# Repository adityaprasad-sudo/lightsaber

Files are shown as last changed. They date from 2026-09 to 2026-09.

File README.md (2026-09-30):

# LightSaber

Pretty much everyone knows what a light saber is Well i am here to make it huhuhaha and share how to make it for #pixl.

# Code

The code is pretty simple and can be found inside the code folder in the GitHub repo you might want to calibrate your sensor(MPU_6050) to match your likings (Calibration is Important).

You can also adjust the thresholds required for a specific action to play. For ex: you can increase the clash threshold to active sound_clash on higher level of impact.

You can also change the color of clash and light saber and add as many modes as you want(as long as your esp32 has storage to afford it) and add sounds(how to add sounds? watch below!)

## How to add custom sounds

1. first find a light saber sounds (light_saber_on, light_saber_strike etc.) not longer then 0.5s to 1sec then convert them to wav format(If not in wav format).
2. upload them on audacity and reduce their band hertz to 11250hz and 8 bit audio and export them.
   lightsaber

3. After that we need to convert them to c++ source files to do that i used a software called HxD to convert wav format to c++ source file.
  lightsaber2

4. After that you will get a c++ source file copy its content only the no. of entires and the data.
5. Paste all those into the SoundData array available in the code folder of the repo(Remember to use correct variable names)

# Circuit diagram

Here is the full circuit diagram

IMG_20260930_211355991_HDR_AE

## how did you get an amplifier ?

I had a old Bluetooth Speaker with an XF-BT90-V3.0 chipset in it in which the bluetooth ic handles the wheater the amplifier would work or not.
The photo attached contains two rectangles

1. **the blue rectangle represents the amplifier ic**
2.  **the pink box represents Bluetooth and audio controller** 
3.   **the orange line is the trace of the audio output from the audio controller to the amplifier** 
4. **The orange arrow represents gnd connection and red arrow represents an mute signal** (*Both are shorted to prevent the amplifier from being in mute mode*)
5. **at the end of the orange trace i connected an blue wire which goes to the dac output of the esp32**

***Note:-** I am using this board also as a charging board since the battery connects to this board and can charge the battery.*

## Parts list
1. ESP32 dev module
2. WS128B leds
3. Amplifier board(Dont have one i told a workaround below)
4. speaker
5. wires
6. MPU 6050
7. power switch
8. Push button
9. Voltage regulator (LM1117t 3.3v)
## 3D files

I made them in free cad to fit all the componets properly and compactly so nothing moves inside when we swing and clash the lightsaber!!!

# Thank you

Thank for reading till here, all the required files could be found in the github repo

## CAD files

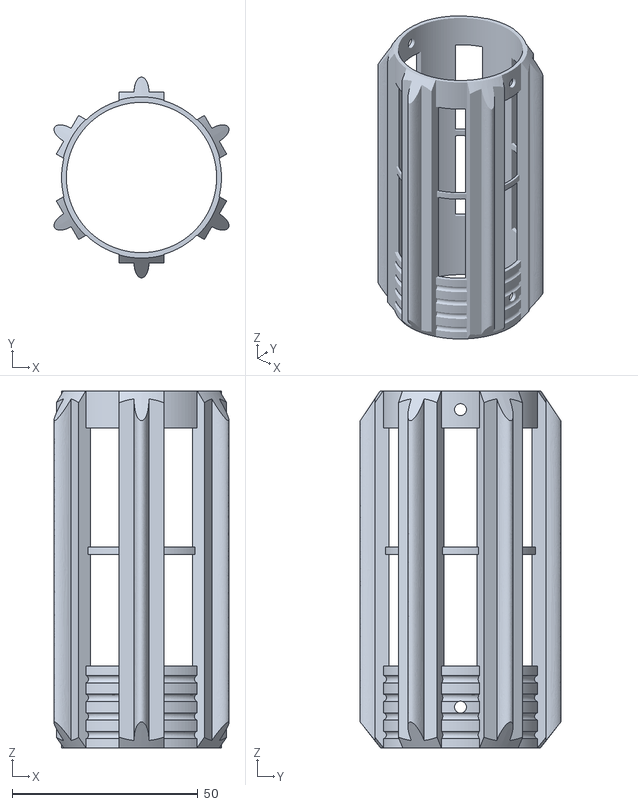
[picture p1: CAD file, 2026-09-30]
3D_Models/llightsaberfinale-handle ribs full.stl
47.0 x 54.0 x 96.0

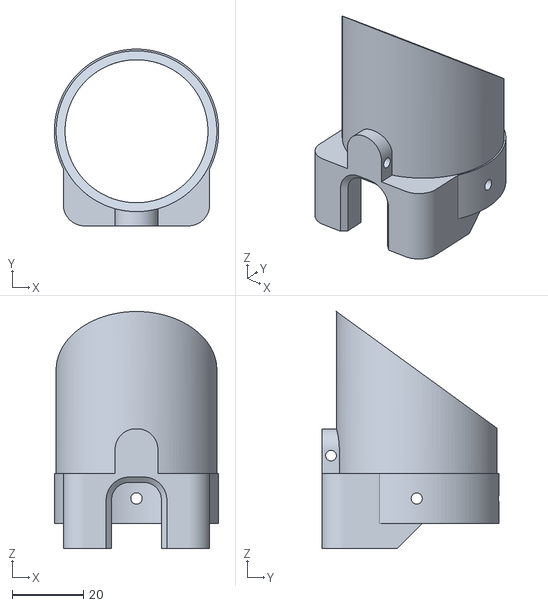
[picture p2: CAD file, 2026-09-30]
3D_Models/llightsaberfinale-top part_.stl
46.0 x 49.5 x 66.3

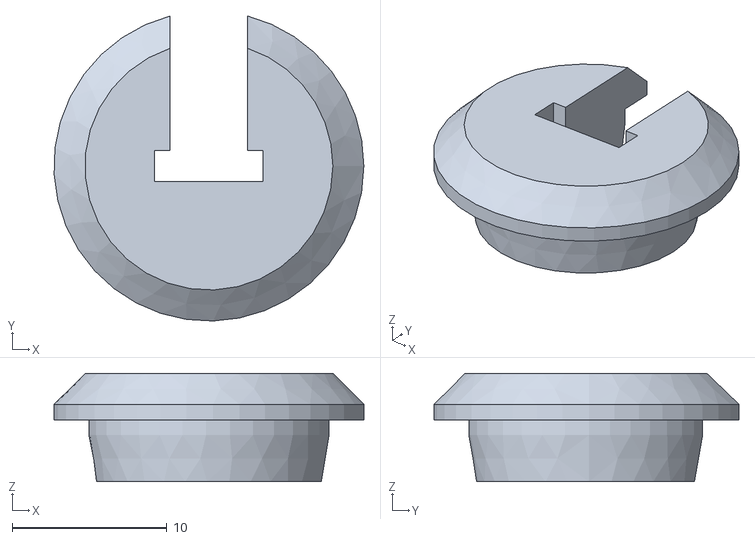
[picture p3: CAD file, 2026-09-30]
3D_Models/llightsaberfinale-blade bottom plug.stl
20.0 x 19.7 x 7.00

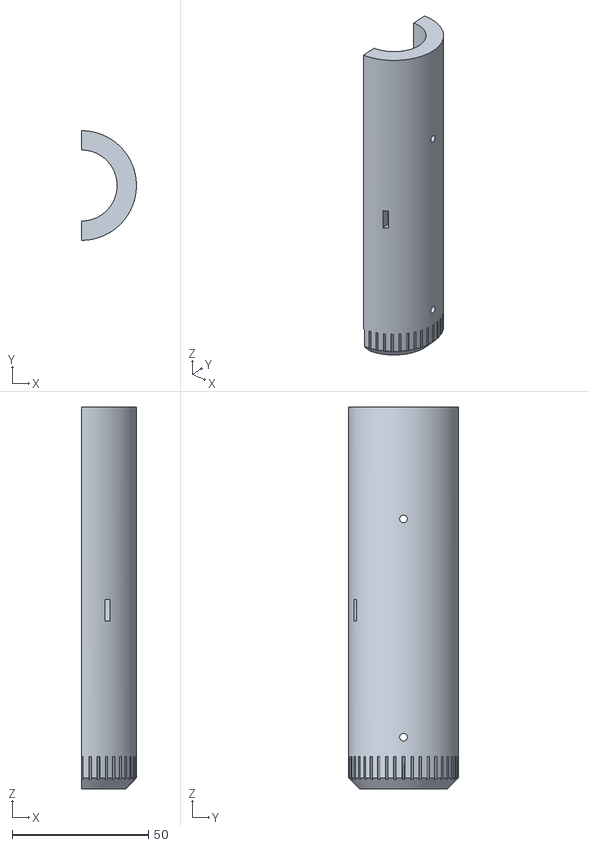
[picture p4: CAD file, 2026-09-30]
3D_Models/llightsaberfinale-Cut026.stl
20.1 x 40.2 x 140.0

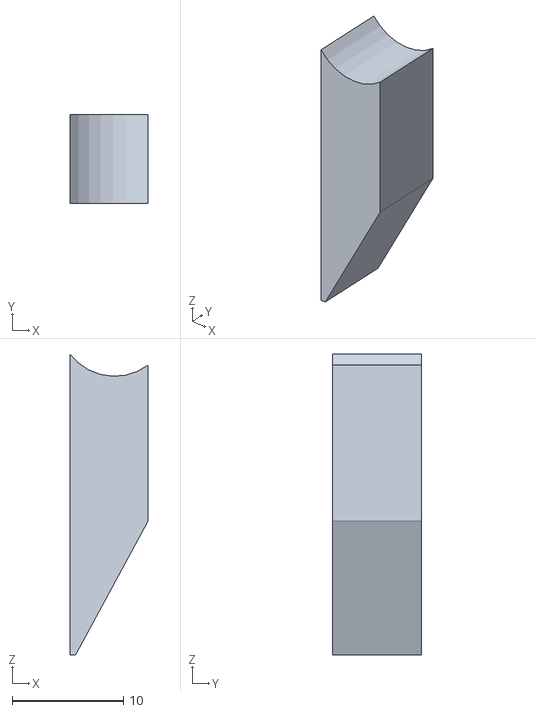
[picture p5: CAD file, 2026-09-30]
3D_Models/llightsaberfinale-mid handle.stl
7.00 x 8.00 x 27.0

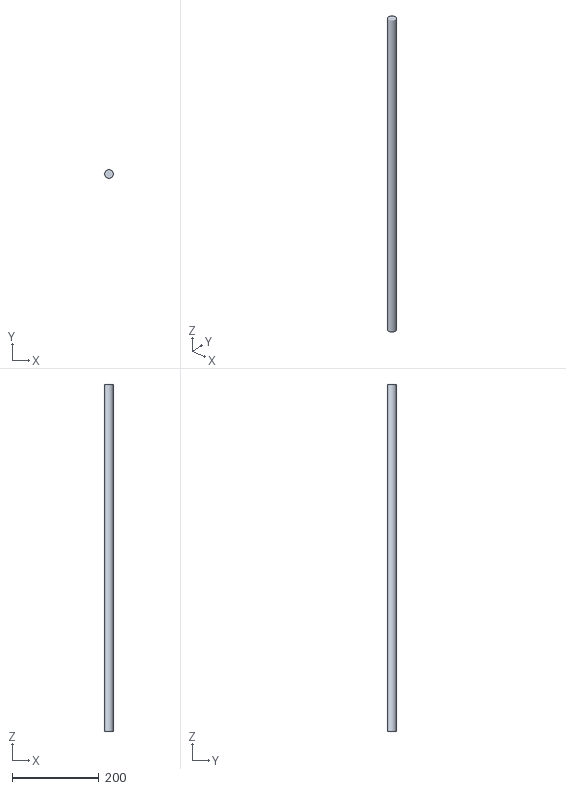
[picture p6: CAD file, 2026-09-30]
3D_Models/llightsaberfinale-blade tube.stl
20.0 x 20.0 x 800.0

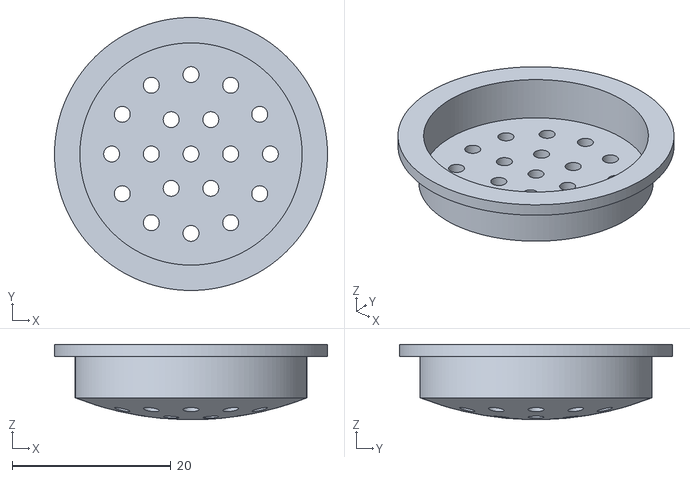
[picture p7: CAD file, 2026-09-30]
3D_Models/llightsaberfinale-speaker grille.stl
34.4 x 34.4 x 9.49

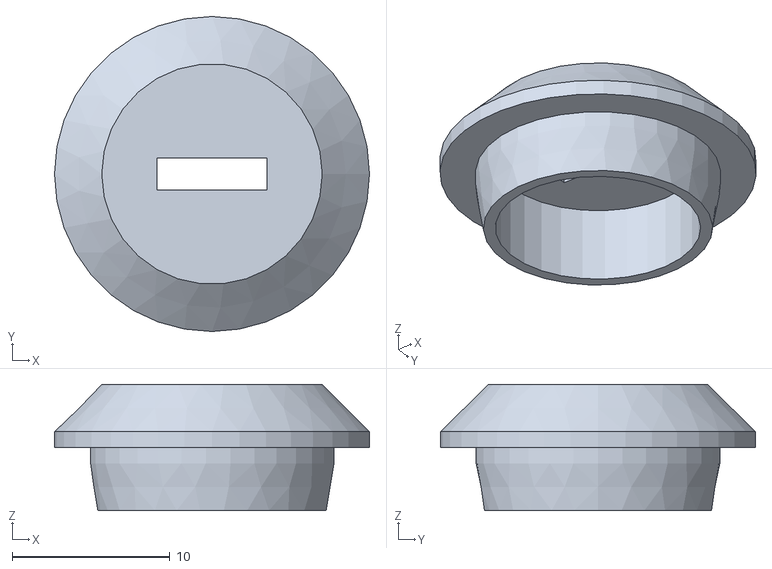
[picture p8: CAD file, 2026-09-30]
3D_Models/llightsaberfinale-blade top plug.stl
20.0 x 20.0 x 8.00

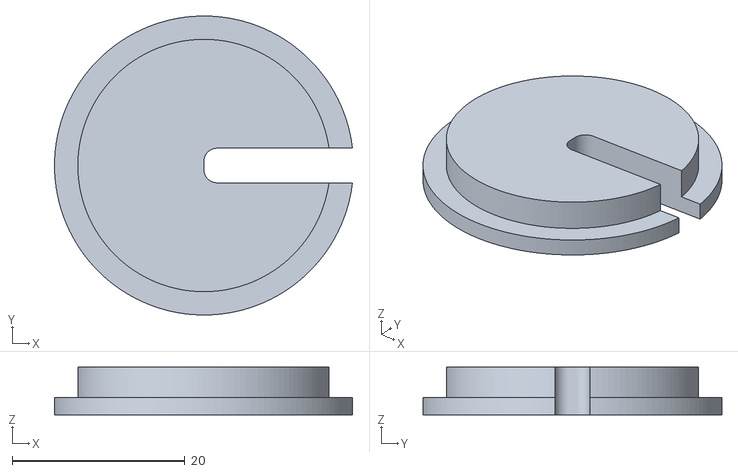
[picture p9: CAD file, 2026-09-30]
3D_Models/llightsaberfinale-speaker stop.stl
34.5 x 34.6 x 5.50

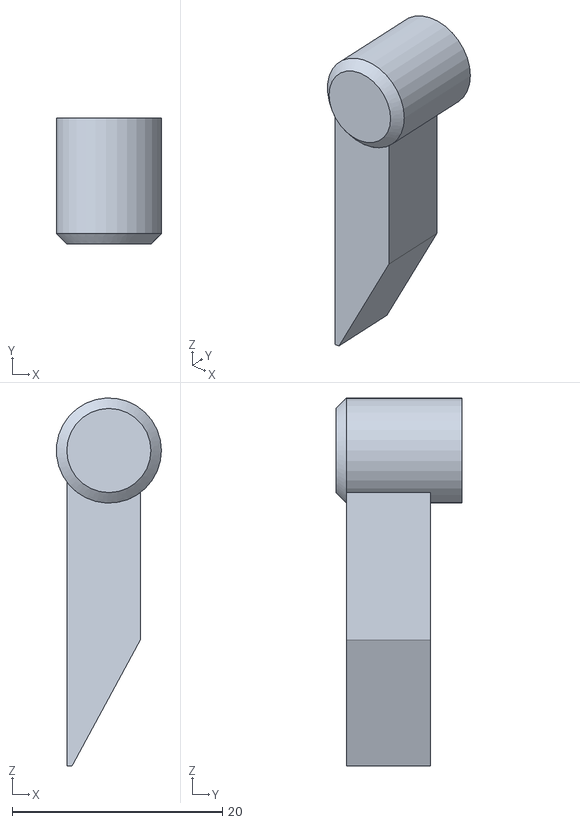
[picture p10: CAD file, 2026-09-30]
3D_Models/llightsaberfinale-mid handle mount.stl
9.97 x 12.0 x 35.0

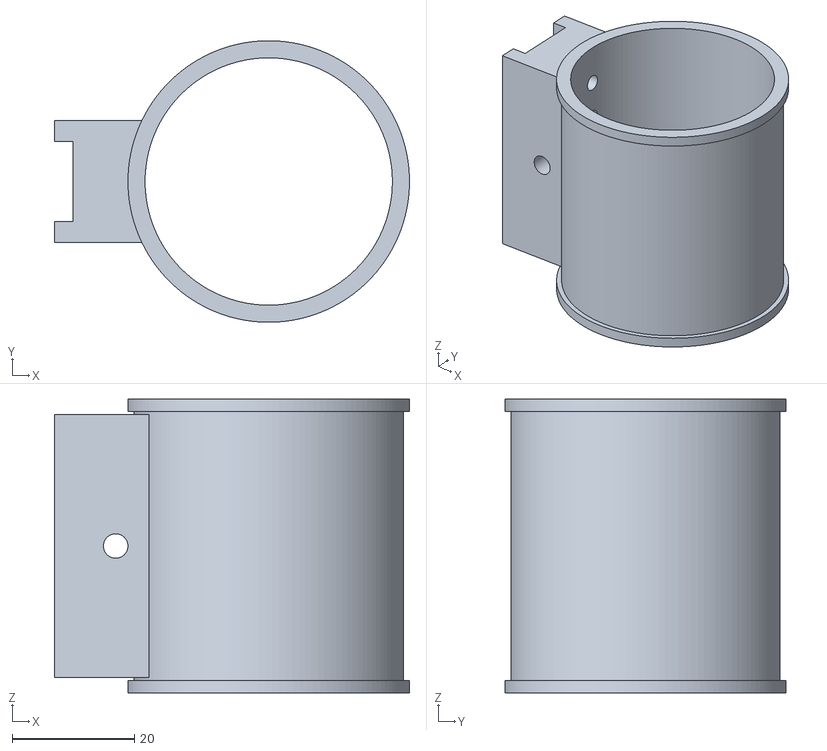
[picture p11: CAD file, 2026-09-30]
3D_Models/llightsaberfinale-middle part.stl
58.0 x 46.0 x 48.0

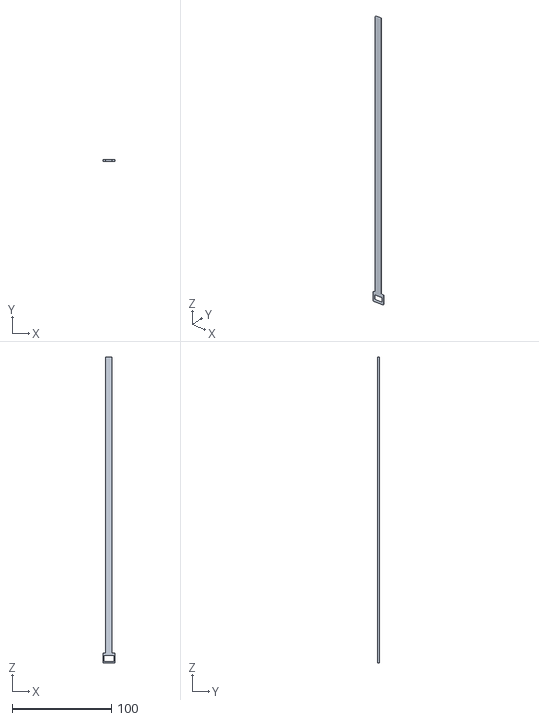
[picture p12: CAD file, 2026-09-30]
3D_Models/llightsaberfinale-led_puller.stl
12.0 x 1.60 x 309.0

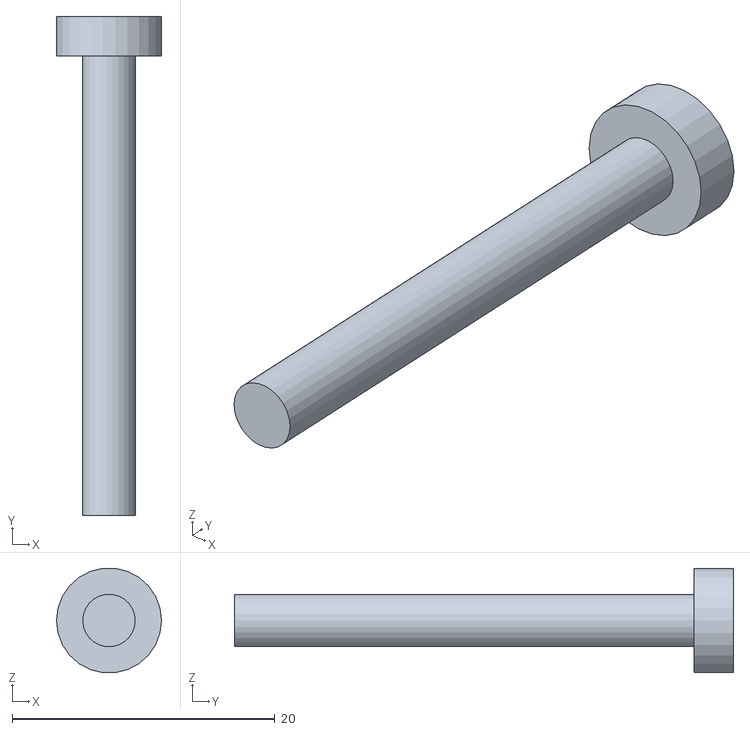
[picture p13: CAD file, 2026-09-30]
3D_Models/llightsaberfinale-m4x35.stl
8.00 x 38.0 x 7.94

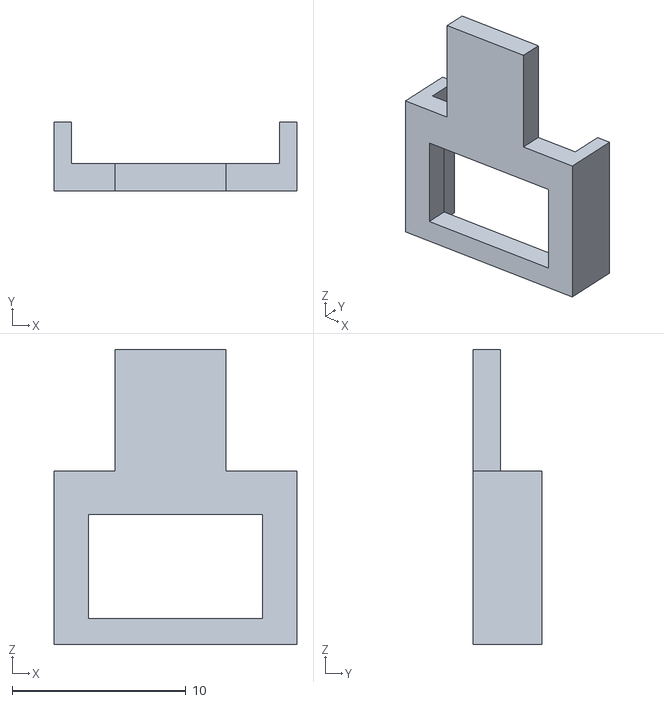
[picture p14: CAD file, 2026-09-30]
3D_Models/llightsaberfinale-led_puller_cover.stl
14.0 x 4.00 x 17.0

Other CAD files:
3D_Models/llightsaberfinale-body top left wide.stl
3D_Models/llightsaberfinale-Cut028.stl
3D_Models/llightsaberfinale-Cut027.stl
3D_Models/llightsaberfinale-screws.stl

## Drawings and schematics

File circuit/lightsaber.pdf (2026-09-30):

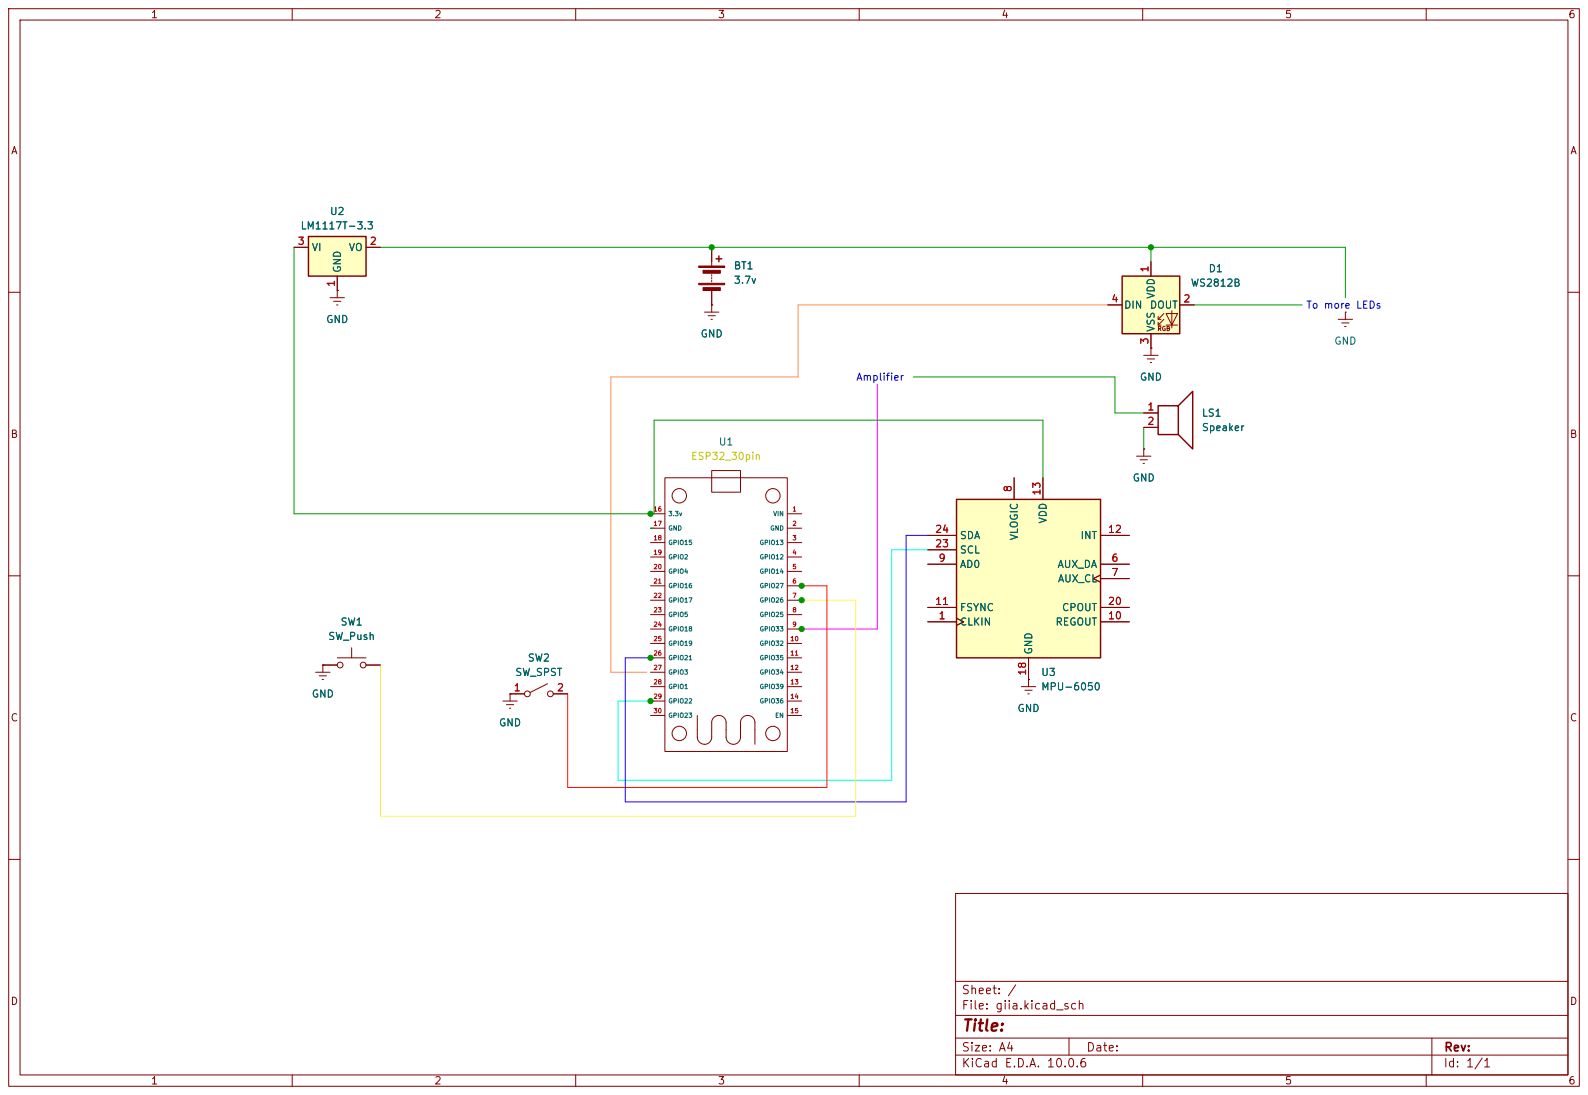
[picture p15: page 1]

Size: A4 | Rev:
KiCad E.D.A. 10.0.6 | Id: 1/1

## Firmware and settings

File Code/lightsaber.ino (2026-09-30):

#include <Wire.h>
#include <FastLED.h>
#include <Adafruit_MPU6050.h>
#include <Adafruit_Sensor.h>
#include "SoundData.h"
#include "XT_DAC_Audio.h"
#define DATA_PIN        3
#define PIN_BTN_POWER   27
#define PIN_BTN_COLOR   26
#define PIN_PWR         14
#define DAC_PIN         25
#define NUM_LEDS        30
CRGB leds[NUM_LEDS];
#define DEBOUNCE_MS       150
#define CLASH_DURATION_MS 350
#define SWING_COOLDOWN_MS 500
#define GYRO_THRESH       50
#define GYRO_MAX         450 
#define SWING_THRESH     100 
#define CLASH_ACCEL      22.0f
#define CLASH_DELTA      16.0f
enum PatternMode : uint8_t {
  MODE_RED  = 0,
  MODE_BLUE = 1,
  NUM_MODES  = 2
};

const CRGB BASE_COLORS[NUM_MODES] = {
  CRGB(180,   0,   0),
  CRGB(  0,   0, 200),
};
const CRGB CLASH_COLOR = CRGB(255, 80, 0);

RTC_DATA_ATTR uint8_t g_mode = MODE_BLUE;
XT_DAC_Audio_Class DacAudio(DAC_PIN, 1);
XT_Wav_Class SoundOn   (sound_on);
XT_Wav_Class SoundOff  (sound_off);
XT_Wav_Class SoundIdle (sound_idle);
XT_Wav_Class SoundSwing(sound_swing);
XT_Wav_Class SoundClash(sound_clash);
Adafruit_MPU6050 mpu;
bool     bladeOn      = false;
bool     clashActive  = false;
uint32_t clashStart   = 0;
uint32_t lastSwingMs  = 0;
float    lastAccelMag = 9.81f;   // 1 g at rest
float    pulsePhase   = 0.0f;
struct ToggleSwitch {
  uint8_t  pin;
  bool     raw      = HIGH;
  bool     state    = HIGH;
  uint32_t lastEdge = 0;

  void begin(uint8_t p) {
    pin = p;
    pinMode(p, INPUT_PULLUP);
    raw = state = digitalRead(p);
  }
  int update() {
    bool newRaw = digitalRead(pin);
    if (newRaw != raw) { raw = newRaw; lastEdge = millis(); }
    if ((millis() - lastEdge) > DEBOUNCE_MS) {
      if (raw != state) {
        bool prev = state;
        state = raw;
        if (prev == HIGH && state == LOW)  return  1;
        if (prev == LOW  && state == HIGH) return -1;
      }
    }
    return 0;
  }

  bool isOn() const { return state == LOW; }
};
struct Btn {
  uint8_t  pin;
  bool     raw      = HIGH;
  bool     state    = HIGH;
  uint32_t lastEdge = 0;

  void begin(uint8_t p) {
    pin = p;
    pinMode(p, INPUT_PULLUP);
  }

  bool pressed() {
    bool newRaw = digitalRead(pin);
    if (newRaw != raw) { raw = newRaw; lastEdge = millis(); }
    bool prev = state;
    if ((millis() - lastEdge) > DEBOUNCE_MS) state = raw;
    return (prev == HIGH && state == LOW);
  }
};

ToggleSwitch swPower;
Btn          btnColor;
void ledsOff() {
  fill_solid(leds, NUM_LEDS, CRGB::Black);
  FastLED.show();
}

void powerOnAnim() {
  DacAudio.Play(&SoundOn,   true);
  DacAudio.Play(&SoundIdle, true);
  SoundIdle.RepeatForever = true;

  CRGB col = BASE_COLORS[g_mode];
  for (int i = 0; i < NUM_LEDS; i++) {
    leds[i] = col;
    FastLED.show();
    DacAudio.FillBuffer();
    delay(300 / NUM_LEDS);
  }
}

void powerOffAnim() {
  DacAudio.Play(&SoundOff, false);
  for (int i = NUM_LEDS - 1; i >= 0; i--) {
    leds[i] = CRGB::Black;
    FastLED.show();
    DacAudio.FillBuffer();
    delay(300 / NUM_LEDS);
  }
  DacAudio.StopAllSounds();
  delay(80);
}
void colorChangeBlink() {
  fill_solid(leds, NUM_LEDS, BASE_COLORS[g_mode]);
  FastLED.show();
  delay(60);
}
void goToSleep() {
  ledsOff();
  DacAudio.StopAllSounds();
  delay(100);
  esp_sleep_enable_ext0_wakeup(GPIO_NUM_27, 0);
  esp_deep_sleep_start();
}
void setup() {
  Serial.begin(115200);

  pinMode(PIN_PWR, OUTPUT);
  digitalWrite(PIN_PWR, HIGH);

  swPower.begin(PIN_BTN_POWER);
  btnColor.begin(PIN_BTN_COLOR);

  FastLED.addLeds<NEOPIXEL, DATA_PIN>(leds, NUM_LEDS);
  FastLED.setMaxPowerInVoltsAndMilliamps(5, 500);
  ledsOff();

  SoundOn.Volume    = 30;
  SoundOff.Volume   = 30;
  SoundIdle.Volume  = 15;
  SoundSwing.Volume = 30;
  SoundClash.Volume = 30;

  Wire.begin(21, 22);
  if (!mpu.begin()) {
    Serial.println("[ERR] MPU6050 not detected — clash/swing disabled.");
  } else {
    mpu.setGyroRange(MPU6050_RANGE_2000_DEG);
    mpu.setAccelerometerRange(MPU6050_RANGE_16_G);
    mpu.setFilterBandwidth(MPU6050_BAND_44_HZ);
    Serial.println("[OK] MPU6050 ready.");
  }

  if (esp_sleep_get_wakeup_cause() == ESP_SLEEP_WAKEUP_EXT0) {
    if (swPower.isOn()) {
      bladeOn = true;
      powerOnAnim();
    } else {
      goToSleep();
    }
  } else if (swPower.isOn()) {
    bladeOn = true;
    powerOnAnim();
  }
}
void loop() {
  DacAudio.FillBuffer();
  int  swChange = swPower.update();
  bool colorBtn = btnColor.pressed();

  if (swChange == 1 && !bladeOn) {
    bladeOn = true;
    powerOnAnim();
  } else if (swChange == -1 && bladeOn) {
    bladeOn = false;
    powerOffAnim();
    goToSleep();
  }
  if (colorBtn && bladeOn) {
    g_mode = (g_mode + 1) % NUM_MODES;
    colorChangeBlink();
    Serial.printf("[COLOR] mode=%s\n", g_mode == MODE_RED ? "RED" : "BLUE");
  }

  if (!bladeOn) {
    delay(10);
    return;
  }
  sensors_event_t a, g, temp;
  mpu.getEvent(&a, &g, &temp);

  float ax = a.acceleration.x;
  float ay = a.acceleration.y;
  float az = a.acceleration.z;
  float gx = g.gyro.x * RAD_TO_DEG;
  float gy = g.gyro.y * RAD_TO_DEG;
  float gz = g.gyro.z * RAD_TO_DEG;

  float accelMag   = sqrtf(ax*ax + ay*ay + az*az);
  float gyroMag    = sqrtf(gx*gx + gy*gy + gz*gz);
  float accelDelta = fabsf(accelMag - lastAccelMag);
  lastAccelMag     = accelMag;
  if (!clashActive && accelDelta > CLASH_DELTA && accelMag > CLASH_ACCEL) {
    clashActive = true;
    clashStart  = millis();
    fill_solid(leds, NUM_LEDS, CLASH_COLOR);
    FastLED.show();
    DacAudio.StopAllSounds();
    DacAudio.Play(&SoundClash, true);
    Serial.printf("[CLASH] accel=%.1f  delta=%.1f\n", accelMag, accelDelta);
  }
  if (clashActive && (millis() - clashStart) > CLASH_DURATION_MS) {
    clashActive = false;
    DacAudio.Play(&SoundIdle, true);
    SoundIdle.RepeatForever = true;
  }
  if (!clashActive &&
      gyroMag > SWING_THRESH &&
      !SoundSwing.Playing &&
      (millis() - lastSwingMs) > SWING_COOLDOWN_MS) {
    DacAudio.Play(&SoundSwing, true);
    lastSwingMs = millis();
  }
  if (clashActive) {
    for (int i = 0; i < NUM_LEDS; i++) {
      if (random8() < 170) {
        leds[i] = CLASH_COLOR;
      } else {
        leds[i] = BASE_COLORS[g_mode];
        leds[i].nscale8(random8(80, 255));
      }
    }

  } else {
    pulsePhase += 0.05f;
    if (pulsePhase > TWO_PI) pulsePhase -= TWO_PI;
    float pulse = 1.0f + 0.15f * sinf(pulsePhase);
    uint8_t swingBoost = 0;
    if (gyroMag > GYRO_THRESH) {
      swingBoost = (uint8_t)constrain(
        map((long)gyroMag, GYRO_THRESH, GYRO_MAX, 0, 90), 0L, 90L);
    }
    CRGB base = BASE_COLORS[g_mode];
    CRGB col(
      constrain((int)(base.r * pulse) + swingBoost, 0, 255),
      constrain((int)(base.g * pulse) + swingBoost, 0, 255),
      constrain((int)(base.b * pulse) + swingBoost, 0, 255)
    );
    fill_solid(leds, NUM_LEDS, col);
  }
  FastLED.show();
  delay(10);
}

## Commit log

2026-09-30 added all the 3d cad files
    [llightsaberfinale-Cut026.stl, llightsaberfinale-Cut027.stl, llightsaberfinale-Cut028.stl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]
2026-09-30 add circuit folder
2026-11-09 Add update about demo assembly and LED attachment
    Added update section with demo video link.
2026-11-09 Update README with video demo of lightsaber assembly
    Added a video demo of the assembled 3D printed parts with WS128B LEDs.
2026-11-09 Update README with demo details and formatting fixes
    Corrected formatting and added details about the new demo with 3D printed parts and WS128B LEDs.
